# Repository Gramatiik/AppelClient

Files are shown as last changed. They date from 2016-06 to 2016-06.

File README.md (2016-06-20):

# Appel Client pour gestion de file d'attente

## But du projet

Ce projet à pour but de simplifier les files d'attente en permettant personnes de faire autre chose pendant leur attente. Pour ce faire, on confiera un "palet" au client, celui-ci vibrera et emettra un signal lumineux lorsque ce sera son tour.

## Origine du projet

J'ai commencé ce projet en mars 2016 lorsqu'un restaurateur me demande comment il pourrait gérer sa file d'attente intelligement et avec les moyens d'aujourd'hui.
Je me suis inspiré d'un produit déjà existant depuis quelques années qui arrive timidement en France, un système d'appel de Client produit par la société **MMCALL**.

Le problème est que ce produit n'est pas open-source et qu'il coûte relativement cher. C'est pourquoi j'ai proposé de réaliser moi-même une **alternative** qui proposerait les même fonctionnalités mais en êtant **open-source et en utilisant des composants à bas prix**.

## Spécifications techniques

### Matériel

Le système sera composé d'un emmeteur à base de Raspberry Pi et d'un nombre "illimité" de récepteurs à base d'Arduino.
La communication sans-fil entre les deux composants sera par RF en 433Mhz car on peut trouver des émetteurs/récepteurs à très bas prix.
Les récepteurs fonctionneront sur des batteries LiPo rechargeables. Pour le reste des composants une nomenclature est mise à disposition dans le dossier _Design_.

### Logiciel

Sur l'émetteur j'ai utilisé pigpio, une librairie Python pour utiliser les pins de la Raspberry Pi. et VirtualWire, en python elle aussi pour la transmission sans-fil.
le reste du programme est en python.

## Montage

### Emmeteur
L'émetteur est alimenté en 12V DC afin de fournir la tension maximale pour le module d'antenne puis cette tension est abaissée et régulée à 5V afin de fournir une alimentation à la carte Raspberry Pi. Cette carte est aussi équipée d'un clavier numérique et d'un dongle wifi pour un accès en SSH. (Un accès en série est également possible).

Premier prototype de l'emmeteur :

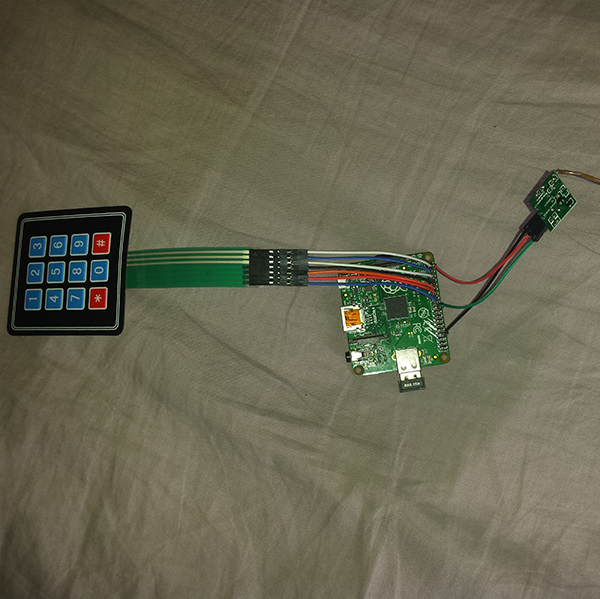
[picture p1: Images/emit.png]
Prototype Emmeteur


Ce prototype est pour l'instant le seul emmeteur réalisé, il est prévu de faire une version améliorée de celui-ci qui sera imprimée en 3D.

### Recepteur

Ce récepteur est composé d'un carte Arduino Pro Mini, d'un step-up pour batterie LiPo (qui fait aussi chargement USB), d'une batterie LiPo (2200mAh ici), et d'une carte qui gère la vibration, une LED pour un signal visuel et le module de réception 433Mhz. Le tout est mis dans une boite en bois (qui sert normalement à contenir un jeu de cartes).

Prototype de la carte de réception (ici sans module pour la batterie) :

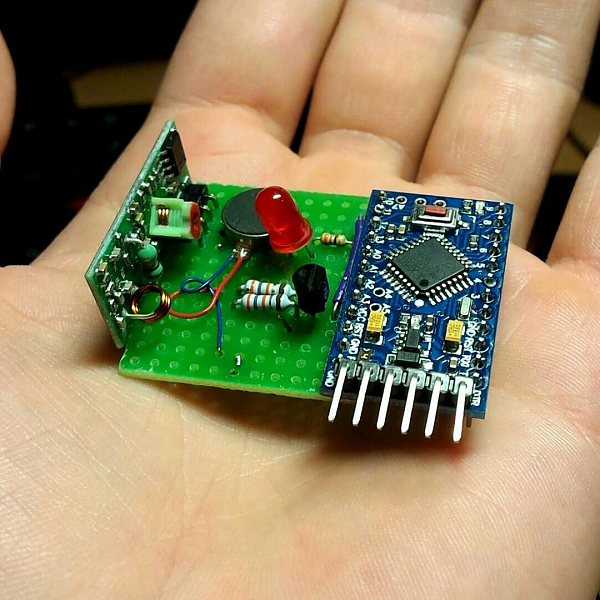
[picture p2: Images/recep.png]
Prototype Recepteur


Circuit final de la carte de réception (sans module de batterie):

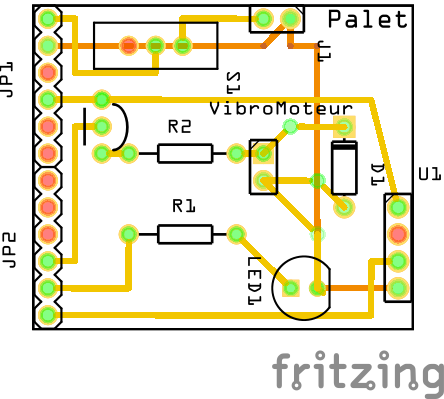
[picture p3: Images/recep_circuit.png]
Circuit Final Recepteur


Version finale du récepteur dans la boîte :

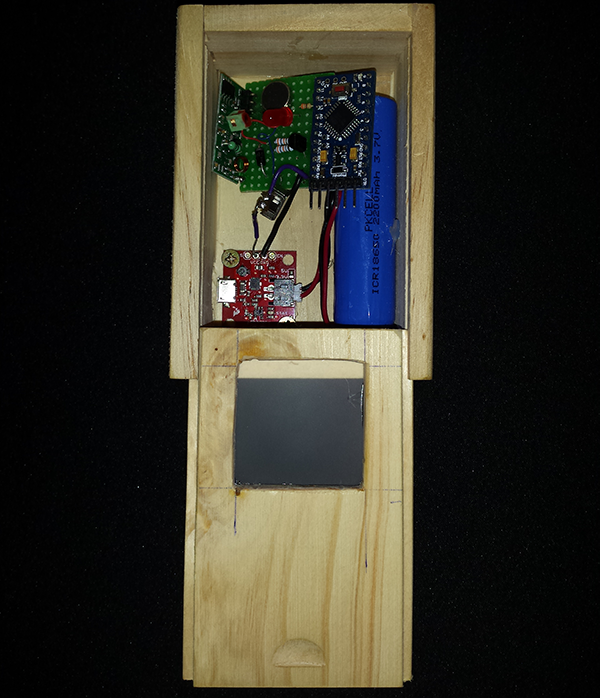
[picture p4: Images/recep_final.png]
Recepteur Boite


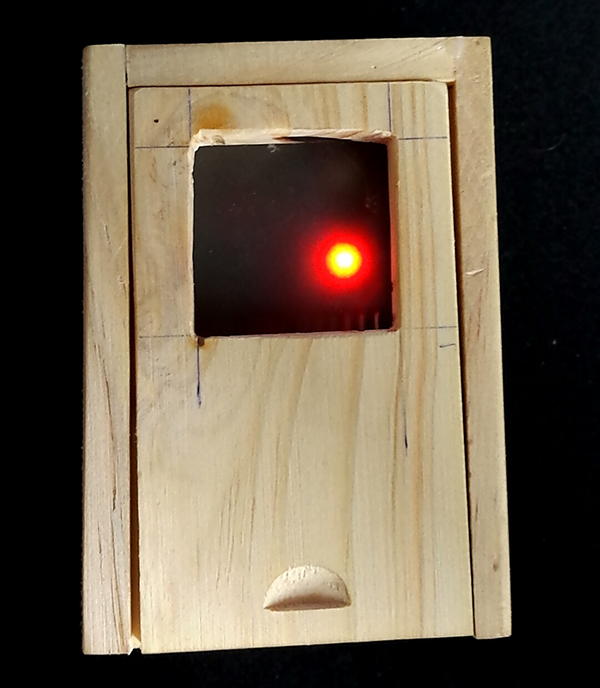
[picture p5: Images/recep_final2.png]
Recepteur Boite2


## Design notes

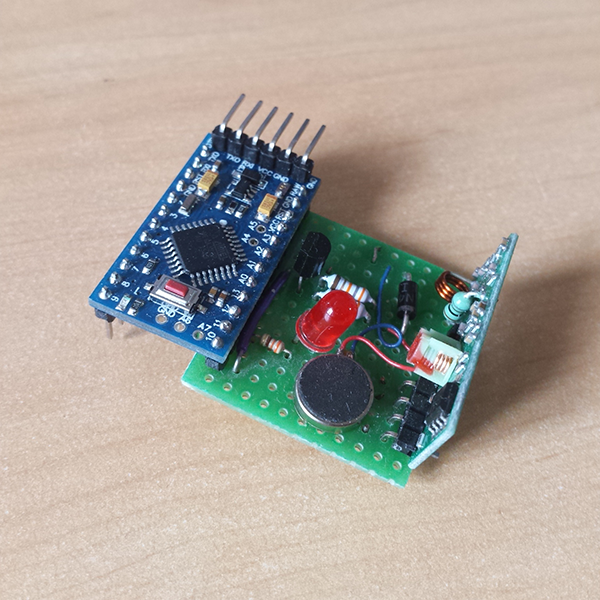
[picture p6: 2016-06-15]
Images/recep2.png

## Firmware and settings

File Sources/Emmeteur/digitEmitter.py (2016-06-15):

#!/usr/bin/env python
# -*- coding: latin-1 -*-

"""
--pins for each cols and rows--

 4 3 2
 v v v
|1|2|3| < 10
|4|5|6| < 22
|7|8|9| < 27
|*|0|H| < 17
"""

import time, pigpio, vw, os, sys

"""
Functions definition
"""
def verifInput(userInput):
	"Verifie si la chaine donnée est un nombre compris entre 0 et 99"
	if userInput.isdigit() and len(userInput) <= 2:
		return True;
	else:
		return False;

def toDigit(index_col, index_row):
	"Convertit le tuple (ligne, colone) du clavier numerique en nombre et le retourne en string "
	digit = None
	digit = 3 * index_row + 1 # nombre minimum pour la ligne
	return str(digit + index_col) # ajouter le numero de la colone pour obtenir le nombre

def sendToPuck(number_str):
	"Envoie un message au palet numero 'number_str'"
	for x in range(0,5):
		while not tx.ready():
			time.sleep(0.1)
		time.sleep(0.1)
		tx.put("SB"+number_str+"F")
	print "\t\tTerminé !"

"""
Initialisation des variables
"""
TX  = 25 # pin GPIO data emetteur RF
BPS = 1000 # vitesse en bauds
pi  = pigpio.pi()
tx  = vw.tx(pi, TX, BPS)

#pins pour le clavier numerique
cols = [4, 3, 2] #pins colones
rows = [10, 22, 27, 17] # pins lignes

current_value = ""

for col in cols:
	pi.set_mode(col, pigpio.INPUT)
	pi.set_pull_up_down(col, pigpio.PUD_UP)
	pi.set_glitch_filter(col, 2500)

for row in rows:
	pi.set_mode(row, pigpio.OUTPUT)
	pi.write(row, 0)

"""
Script principal
"""
while 1:
	for col in enumerate(cols):
		if pi.read(col[1]) == 0:
			for row in enumerate(rows):
				
				pi.write(row[1], 1)
				time.sleep(0.005) # petit interval entre chaque tranqition
				
				if pi.read(col[1]) == 1:
					tch = toDigit(col[0], row[0]) # dernier digit appuyé
					
					if tch == "10": # touche validé "*" appuyée
						if current_value != "" and verifInput(current_value):

							if int(current_value) <= 9:
								current_value = current_value.zfill(2) # le nombre doit faire 2 caractères
								
							print "Sending  ! your value is {0}".format(current_value)
							sendToPuck(current_value)

						else:
							print "Veuillez entrer un nombre valide..."
						
						current_value = "" # remise à zero de la valeur actuelle après envoie
					
					elif tch == "12": # appuie sur le bouton reset "#"
						current_value = ""
					
					elif tch == "11": # appuie sur la touche "0"
						current_value = current_value + "0"
					
					else:
						current_value = current_value + tch

				pi.write(row[1], 0)
				time.sleep(0.005) # petit interval entre les transitions
			
			time.sleep(0.2) #temps minimum entre 2 appue (pour eviter les repetitions)

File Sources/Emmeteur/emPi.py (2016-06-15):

#!/usr/bin/env python
# -*- coding: latin-1 -*-

"""
SCRIPT D'ENVOIE DE MESSAGE EN LIGNE DE COMMANDE PAR ARGUMENT
"""

import time, pigpio, vw, os, sys

def usage():
   return "usage : Passer le numero du palet a faire sonner en parametre au script"

def verifInput(str):
   "Vérifie si la chaine est un nombre entre 0 et 99"
   if str.isdigit() and len(str) <= 2:
      return True;
   else:
      return False;

TX  = 25 # pin GPIO data emetteur RF
BPS = 1000 # vitesse en bauds
pi  = pigpio.pi()
tx  = vw.tx(pi, TX, BPS)

if len(sys.argv) == 2:

   objStr = sys.argv[1]
   
   if verifInput(objStr): # 0 <= objstr <= 99 ?
      if int(objStr) <= 9 :
         objStr = objStr.zfill(2) # pour que le nombre fasse toujours 2 caractères

      print "\tEnvoi de la trame au palet {}".format(objStr)

      for x in range(0,5):
         while not tx.ready():
            time.sleep(0.1)
         time.sleep(0.1)
         tx.put("SB"+objStr+"F")
         print "\t\tEssai {}".format(x)
   else:
      print "veuillez entrer un nombre valide..."
else:
   print usage()

tx.cancel()
pi.stop()

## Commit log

2016-05-19 Update matrix source file now working (minor bug fixes needed)
    [matrix.py]
2016-05-22 PCB design fixes + matrix.py tweaks
    [pcbPalet.fzz]
2016-05-22 Add Image of PCB and clean code of emitter
2016-05-22 Correct bug in verifInput
    [digitEmitter.py]
2016-05-22 Correct bug in digitEmitter
    [digitEmitter.py]
2016-06-07 Update PCB image and design
    [pcbPalet.fzz]
2016-06-10 Minor bug fixes in code
    [MontagePalet.fzz]
2016-06-15 supprimé les fichiers d'exemple de VirtualWire
2016-06-15 ajout de nouveaux commentaires sur les sources emmeteur et recepteur
2016-06-20 creation d'un programme de test pour les circuits imprimés
2016-06-20 Ajout de differents patterns de vibration et re-organisation du dossier sources des Palets
    [VW_test1.ino, test_palet.ino]
2016-06-23 Correction d'une erreur sur le PCB
    [pcbPalet.fzz]
